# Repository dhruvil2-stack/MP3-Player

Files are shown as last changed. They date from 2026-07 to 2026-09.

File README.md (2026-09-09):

# Dhruvil's MP3 Player

---

## Documentation

For detailed technical documentation including component selection, design calculations, and system architecture:

📄 [Technical Documentation](docs/TECHNICAL_DOCS.md)

---

## Overview

This is a homemade portable MP3 player with a focus on clean audio, compact design, and learning analog-digital design for pcbs. This player plays MP3 files off an SD card and features a simple playback interface with volume control and track navigation, it does however support multiple files types such as wav,flac,midi,mp1-3.

The entire project is open-source — firmware, PCB design files, and 3D-printed case models are all available on GitHub.

---

## Features

- Compact 4-layer PCB measuring 60.72 mm X 86.85 mm, designed in Altium
- Separate Analog and Digitial LDO's to minimize analog noise and maintain audio quality
- TFT display showing track metadata: song name, album, artist, and duration
- USB charging with BQ24074 battery management IC
- Long battery life — runs for ~20 hours on a single charge with a 3.7V 2600mah battery, this will depend heavily on the screen brightness
- Custom 3D-printed enclosure designed in Fusion360

---

## Hardware

The player is built around an ESP32 microcontroller paired with a VS1053b audio DAC for MP3 decoding and audio ouput. A BQ24074 handles battery charging with power and data done over USB C-2.0, and all components are packed onto a 4-layer PCB with a SIG-GND-PWR-SIG stackup. A gpio expander PCF8575PWR is used to handle volume and playback switch inputs.

The PCB was designed in Altium. Components are hand-soldered and by a hot-air gun.

---

## Firmware

The ESP32 communicates with the SD card over SPI using standard libraries for FAT32 filesystem access. The VS1053b also speaks SPI, so firmware handles both interfaces efficiently.

The ESP32 also only uses 1 core to prolong battery life, more about this is listed in the documentation file.

Track metadata (song name, album, artist, duration) is parsed from the SD card and displayed on the TFT screen in real-time.

---

## Enclosure

The case is 3D-printed using Fusion360 and designed to snugly fit the PCB and battery. It uses a simple two-piece snap-fit design printed in PLA.

---

## Build Your Own

Everything you need to build your own is available in this repository:

- **PCB Design** — Altium project files, schematic, and Gerbers
- **Firmware** — ESP32 code, SPI drivers, and metadata parsing
- **Enclosure** — Fusion360 STL files for top and bottom case halves
- **Bill of Materials** — Full parts list with component sources

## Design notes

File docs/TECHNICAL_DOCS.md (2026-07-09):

# MP3 Player - Technical Documentation

## Table of Contents

- [Power Management](#power-management)
- [Microcontroller Selection](#microcontroller-selection)
- [Audio Decoder Selection](#audio-decoder-selection)
- [Display Selection](#display-selection)
- [Enclosure Design](#enclosure-design)

---

## Power Management

### Battery Charging - BQ24074

The BQ24074 was selected as the battery charging IC due to its integrated power-path management and ability to support fast charging currents up to 1.5A. The charging current is configured using an external resistor connected to the ISET pin.

**Charging Current Calculation:**

$$I_{CHG} = \frac{K_{ISET}}{R_{ISET}}$$

$$R_{ISET} = \frac{K_{ISET}}{I_{CHG}} = \frac{890\ \text{A}\cdot\Omega}{0.80\ \text{A}} = 1.1125K\ \Omega \approx 1.1K\ \Omega$$

**Battery Specification:**

| Parameter | Value |
|---|---|
| Chemistry | Lithium-Ion (Li-ion) |
| Nominal Voltage | 3.7V |
| Maximum Voltage | 4.2V |
| Capacity | 1500mAh |
| Charging Current | 0.80A (Fast Charge) |

**EN Pin Configuration:**

The EN1 and EN2 pins configure the input current limit based on the USB power source:

| EN1 | EN2 | Input Current Limit | Configuration |
|-----|-----|---|---|
| 0 | 0 | USB 100mA (SDP) | Not Used |
| 1 | 1 | USB 500mA | Not Used |
| 0 | 1 | Adapter 0.80A | **Selected** |
| 1 | 0 | Adapter 1.5A | Not Used |

**Selected Configuration:**

The BQ24074 is configured with **EN1 = 0** and **EN2 = 1**, setting the input current limit to **0.80A**. This configuration was chosen to:

- Keep charging time to be relativelty fast while staying within the safe limits of charging a lipo
- Allow the BQ24074's power-path to manage battery charging and system power simultaneously
- Provide adequate headroom for system operation while charging

### Voltage Regulation - AP2112K-3.3V and AP2112K-1.8V

The AP2112K series LDOs were selected for voltage regulation based on the following specifications:

| Parameter | Value |
|---|---|
| Dropout Voltage | 250mV typical at 600mA load |
| Output Current | Up to 600mA |
| Package | SOT-23-5 |
| Features | Enable pin, thermal protection, short-circuit protection |

**Power Rails:**

| Rail | Voltage | Regulator | Supply | Purpose |
|---|---|---|---|---|
| 3.3V | 3.3V | AP2112K-3.3 | 3.7V Li-ion | ESP32, ST7735 display, VS1053b IOVDD/AVDD, SD card, logic levels |
| 1.8V | 1.8V | AP2112K-1.8 | 3.7V Li-ion | VS1053b core voltage (CVDD) |

**Selection Rationale:**

- Low dropout voltage (250mV typical) enables efficient operation from a 3.7V Li-ion battery while maintaining stable output voltages
- 600mA output capacity sufficient for all onboard components
- Enable pin allows controlled power sequencing and low-power standby modes
- Built-in over-temperature and short-circuit protection enhance system reliability

**VS1053b Power Requirements:**

The VS1053b requires two separate power supplies:

- **IOVDD (3.3V):** Powers the digital I/O pins and SPI interface
- **CVDD (1.8V):** Powers the internal core processor and DSP

The 1.8V rail is critical for proper VS1053b operation. The AP2112K-1.8 provides a stable, low-noise supply to ensure consistent audio decoding performance.

---

## Microcontroller Selection - ESP32

The ESP32 was selected as the main controller for the following reasons:

**Advantages:**

- Extensive library support for ST7735 TFT display drivers (ESP-IDF and Arduino frameworks)
- Multiple SPI peripherals allow simultaneous communication with VS1053b, SD card, and display without bus contention
- Sufficient processing power for metadata parsing, audio streaming control, and UI updates
- Large community and extensive documentation for troubleshooting
- Built-in Wi-Fi and Bluetooth (future expandability for wireless streaming or OTA updates)

**Pin Allocation:**

| Peripheral | Interface | ESP32 Pins |
|---|---|---|
| VS1053b | SPI | VSPI (MOSI, MISO, SCK, CS, DREQ, RST) |
| SD Card | SPI | VSPI or HSPI |
| ST7735 Display | SPI | VSPI (CS, DC, RST) |
| Buttons | GPIO | Multiple input pins |
| BQ24074 | GPIO | EN1, EN2, CHG status |

---

## Audio Decoder Selection - VS1053b

The VS1053b was selected as the audio codec based on the following factors:

**Key Specifications:**

| Parameter | Value |
|---|---|
| Formats Supported | MP3, AAC, Ogg Vorbis, WMA, FLAC, WAV, MIDI |
| Interface | SPI |
| Headphone Output | Direct drive (no external amp required) |
| Core Voltage (CVDD) | 1.8V |
| I/O Voltage (IOVDD) | 3.3V |

**Selection Rationale:**

- Well-documented datasheet with comprehensive technical reference
- Successfully prototyped on a breakout board prior to PCB integration
- Integrated headphone amplifier drives headphones directly (load impedance ≥ 16Ω)
- Eliminates need for external amplifier, reducing current consumption
- Supports multiple audio formats for versatility

**Power Supply Requirements:**

The VS1053b requires two separate voltage rails:

- **CVDD (1.8V):** Core voltage for internal processor and DSP. Requires stable, low-noise supply.
- **IOVDD (3.3V):** Digital I/O voltage for SPI communication and control pins.
- **AVDD (3.3V):** Analog Power Supply 
The AP2112K-1.8 was selected for the CVDD rail due to its low dropout voltage and low-noise output, ensuring reliable audio decoding performance.

**Headphone Output:**

Typical earbuds have an impedance of 32Ω, which is well within the VS1053b's drive capability (minimum 16Ω load). The VS1053b uses a DC-coupled output with a 1.25V reference (GBUF), allowing direct headphone connection without coupling capacitors.

---

## Display Selection - ST7735

The ST7735 TFT display was selected for the following reasons:

**Key Specifications:**

| Parameter | Value |
|---|---|
| Resolution | 160x128 |
| Interface | SPI |
| Color Depth | 65K colors (RGB565) |
| Operating Voltage | 3.3V |

**Selection Rationale:**

- Existing driver libraries available for ESP-IDF and Arduino
- SPI interface minimizes pin count
- Sufficient resolution for track metadata display
- Color capability enables clear UI elements

---

## Enclosure Design - 3D Printed

The enclosure was designed using Tinkercad for ease of iteration.

**Design Specifications:**

- Material: PLA
- Assembly: Snap-fit (no screws or adhesives required)
- Custom pockets for PCB and battery
- Low-profile design fits comfortably in hand

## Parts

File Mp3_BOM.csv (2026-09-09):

Name | Description | Designator | Footprint | LibRef | Quantity | LCSC PART #
100nF |  | C1, C22, C35, C36, C37, C42, C43, C44, C45, C48, C50, C51, C52, C56, C68 | CAPC1005X55X25ML05T10 | CMP-2008-02013-1 | 15 | C1525
1uF | Cap Ceramic 1uF 10V X5R ±10% SMD 0402 +85°C Paper T/R | C2, C38, C53, C57, C58, C59, C60, C61, C65, C66 | FP-CL511-IPC_C | CMP-13271-001936-1 | 10 | C52923
10uF | 10uF 16V ±10% 3O 1206 SMD Tantalum Capacitor | C14, C41, C49 | FP-TAJA-MFG | CMP-1661-00004-2 | 3 | C7171
4u7 | Cap Ceramic 4.7uF 10V X5R ±20% SMD 0402 +85°C Paper T/R | C39, C40, C47 | FP-CL282-IPC_C | CMP-13271-000548-1 | 3 | C23733
CL10A226MQ8NRNC | CL10 Series 22 uF 6.3 V Â±20 % Tolerance X5R SMT Multilayer Ceramic Capacitor | C46, C67 | CAPC1608X100N | CMP-001-00086-1 | 2 | C59461
33pF | Cap Ceramic 33pF 50V C0G ±5% SMD 0402 +125°C Paper T/R | C54, C55 | FP-CL790-IPC_C | CMP-13271-001471-1 | 2 | C1562
47nF | Cap Ceramic 47nF 50V X7R ±10% Pad SMD 0603 +125°C T/R | C62 | FP-CL10-IPC_A | CMP-13271-001056-1 | 1 | C1622
10nF |  | C63, C64 | CAPC1005X55X25LL05T05 | CMP-1034-01870-2 | 2 | C15195
RED | Red 0603 Light Emitting Diodes | D5 | LED_KT-0603R | CMP-004-00031-1 | 1 | C2286
White | LED Uni-Color Blue, 76 mW, 20 mA, -20 to 80 degC, 2-Pin SMD, RoHS, Tape and Reel | D6 | LTST-C190TBKT-2_V | CMP-007-00026-2 | 1 | C2290
USBLC6-2SC6 | Integrated Circuit | IC1 | SOT95P280X145-6N | USBLC6-2SC6 | 1 | C2827654
AP2112K-3.3TRG1 | IC REG LINEAR 3.3V 600MA SOT-25 | IC5, IC7 | DIODES SOT-23-5 W5 | AP2112K-3.3TRG1 | 2 | C51118
AP2112K-1.8TRG1 | IC REG LINEAR 1.8V 600MA SOT-25 | IC6 | DIODES SOT-23-5 W5 | AP2112K-1.8TRG1 | 1 | C176944
USB4105-GF-A-120 | USB CONN, 2.0 TYPE C, RCPT, 16POS, SMT; USB Connector Type:USB Type C; USB Standard:USB 2.0; Gender:Receptacle; No. of Positions:16Positions; Connector Mounting:Surface Mount, Through Hole Mount; Orientation:Right Angle RoHS Compliant: Yes | J3 | GCT_USB4105-GF-A-120 | CMP-002-00071-1 | 1 | C5184243
SLLB120300 | Electromechanical Switch Lever and Push Switch ON OFF SPST 0.01A T/R | PLAYBACK, VOLUME | SW_SLLB120300 | CMP-011-00013-2 | 2 | C255512
AO3401A | P-Channel MOSFET, 30 V, 4 A, -55 to 150 degC, 3-Pin SOT-23-3L, RoHS, Tape and Reel | Q1 | AO-SOT-23-3L_V | CMP-2000-05778-1 | 1 | C15127
10K | RES Thick Film, 10kO, 5%, 0.063W, 200ppm/°C, 0402 | R1, R2, R3, R4, R5, R6, R36, R44, R45, R46, R47, R51, R54, R55, R57, R58, R65, R72 | FP-CRCW0402-e3-IPC_B | CMP-2002-08136-3 | 18 | C25744
5K1 | RES Thick Film, 5.11kO, 1%, 0.063W, 100ppm/°C, 0402 | R37, R40, R66, R67, R73 | FP-CRCW0402-e3-IPC_C | CMP-2002-00117-2 | 5 | C25905
0402WGF1101TCE | 1.1K Ohm 1/16W Thick Film Resistor 0402 Chip - Surface Mount | R38, R39, R41, R43 | RESC1005X40N | CMP-009-00177-1 | 4 | C22764
0402WGF1003TCE | 100K Ohm 1/16W Thick Film Resistor 0402 Chip - Surface Mount | R42, R48, R49, R50, R53, R56 | RESC1005X40N | CMP-009-00178-1 | 6 | C25741
CRCW04021M00FKEDHP | Resistor;Thick Film;1 Megohms;0.125 W;1%;SMT;0402;TCR 37 ppm/DegC | R52 | RESC1005X40N | CMP-009-00179-1 | 1 | C26083
0603WAF200JT5E | 20 Ohm 1/10W Thick Film Resistor 0603 Chip - Surface Mount | R62, R64 | RESC1608X55N | CMP-009-00181-1 | 2 | C22950
0402WGF100JTCE | 10 Ohm 1/16W Thick Film Resistor 0402 Chip - Surface Mount | R63 | RESC1005X40N | CMP-009-00180-1 | 1 | C25077
TS-1187A-B-A-B | SPST 50mA @ 12VDC Top Actuated Round Button 160gf SMD Tactile Switches RoHS | S1, S2 | SW_TS-1187A-B-A-B | CMP-047-000000-1 | 2 | C318884
BQ24074RGTRG4 | USB-Friendly Li-Ion Battery Charger and Power-Path Management IC, 10.5 V OVP, 4.3 V, -40 to 85 degC, 16-pin QFN (RGT), Green (RoHS & no Sb/Br) | U4 | RGT16-1700X1700TP | CMP-0321-00219-1 | 1 | C54313
 | VS1053B MP3/WAV/OGG/MIDI Player & Recorder (CODEC) Chip | U5 | LQFP48-0.5-7X7MM | CMP-009-000000-1 | 1 | C9922
 | USB Bridge, USB to UART USB 2.0 UART Interface 28-QFN (5x5) | U6 | QFN28G_0.5-5X5MM | CMP-013-000000-1 | 1 | C6568
PCF8575CPW | Remote 16-Bit I2C and SMBus I/O Expander with Interrupt Output, 4.5 to 5.5 V, -40 to 85 degC, 24-pin TSSOP (PW), Green (RoHS & no Sb/Br) | U7 | PW0024A_N | CMP-0314-00372-2 | 1 | C2652277
12.288 MHz | Crystal 12.288MHz ±20ppm (Tol) ±30ppm (Stability) 18pF FUND 80? 4-Pin SMD T/R | Y2 | FP-ABM8G-MFG | CMP-27762-013733-1 | 1 | C519811

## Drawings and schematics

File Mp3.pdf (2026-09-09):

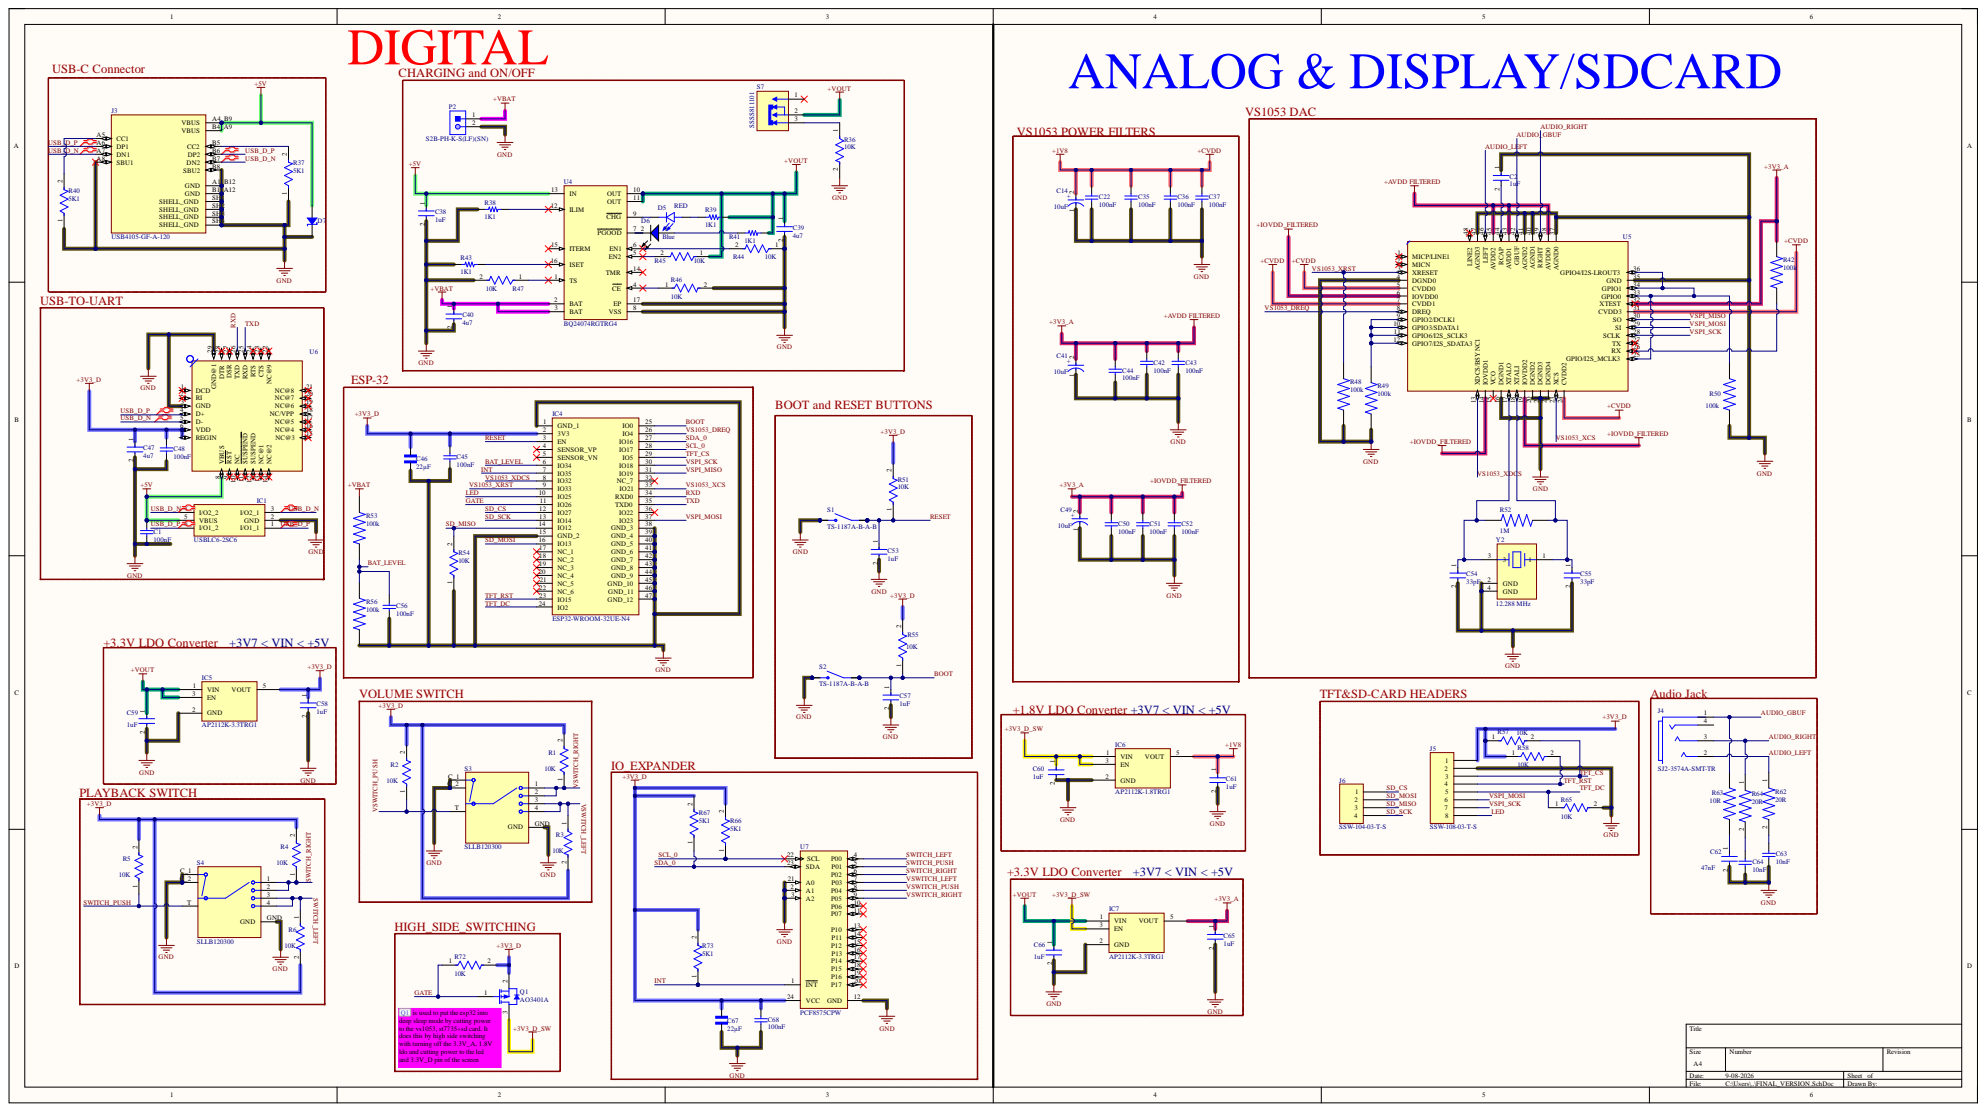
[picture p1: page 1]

TXD 26 DSR 27 DTR 28 GND@1 29

NC@9 22 CTS 23 RTS 24 RXD 25

S D_MIS | V

ed to put the e
ep mode by cutting pow

s thi
ldo and cutting pow
and 3.3V_D pin of the s

s by high s
th turning off the 3.3V_A, 1.8V

F i l e : C: \U s ers \..\ FIN A L_V ERSIO N.S chDoc | Dra wn By:

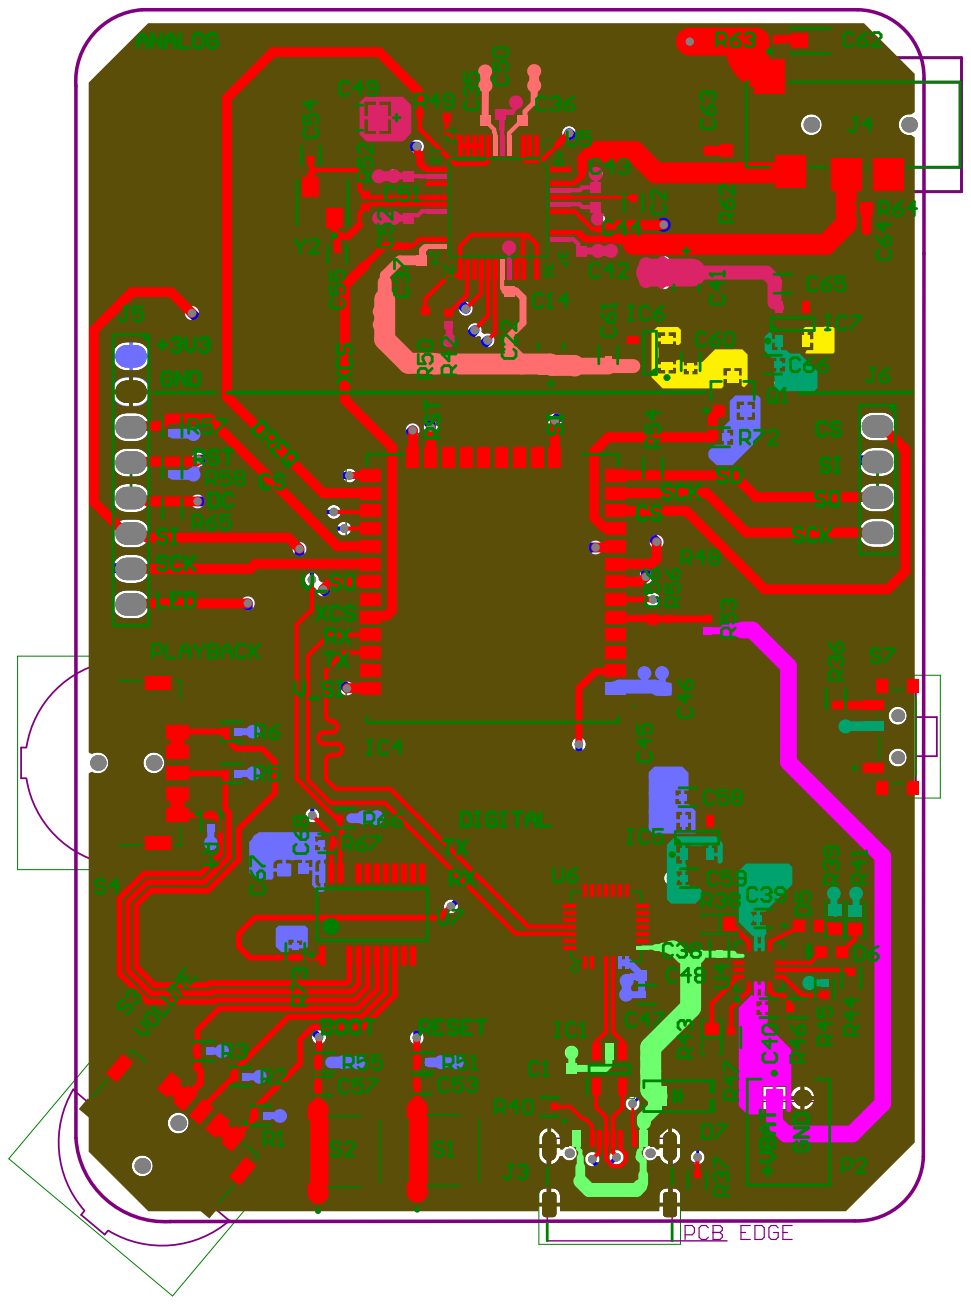
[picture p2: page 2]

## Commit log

2026-07-09 Add files via upload
    Schematic
    [mp3.~(41).SchDoc]
2026-09-09 Add files via upload
    PDF of Schematic and PCB Design containing Layer 1 (SIG) and Layer 2 (GND)
2026-09-09 Add files via upload
    BOM of the pcb, it also includes jlcpcb component numbers to let jlc handle soldering and manufacturing. It does not have the 8/4 female header pin component, or the on/off switch, S3/S4 switches or 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
    [Mp3_BOM.csv]
2026-09-09 Add files via upload
    Pick and Place file for the PCB
    [Pick Place for FINAL_VERSION_MP3.csv]
2026-09-09 Rename Pick Place for FINAL_VERSION_MP3.csv to Pick and Place.csv
    [Pick and Place.csv]
2026-09-09 JLCPCB Gerber Files
    JLC PCB gerber files for manufacturing
2026-11-08 Rename case_2026-10-22_base_nov.stl to Base.stl
    This is the base of the case
2026-11-08 Rename case_2026-10-22_lid_nov.stl to Lid.stl
    This is the LID of the pcb, please print this with full supports and I leave the supports on the upper part as they provide some extra support. The lid is for sure a work in progress, and I will upda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
